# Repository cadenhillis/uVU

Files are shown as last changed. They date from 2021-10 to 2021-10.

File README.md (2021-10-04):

# uVU
A tiny analog VU meter

Uses the LM3915 to do a fun little VU display on an LED bargraph.

The pcb is a little hard to assemble, but bending the bargraph's pins out before soldering everything helps.

I didn't get great results with the two tuning pots -- they seemed to almost fight eachother.
Maybe adding some smoothing to make the sound wave more DC-like or only having 1 pot in the future will help things.

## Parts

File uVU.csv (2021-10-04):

Source: | E:\Projects\8. Micro VU Meter and BMS\uVU\uVU.sch
Date: | 6/15/2021 8:17:00 PM
Tool: | Eeschema (5.1.9)-1
Generator: | C:\Program Files\KiCad\bin\scripting\plugins/bom_csv_grouped_by_value.py
Component Count: | 19
Individual Components:
Item | Qty | Reference(s) | Value | LibPart | Footprint | Datasheet
 |  | C1 | 10uF | Device:CP1 | Capacitor_SMD:CP_Elec_4x3 | 865090140001
 |  | C2 | 10uF | Device:CP1 | Capacitor_SMD:CP_Elec_4x3 | 865090140001
 |  | C3 | 10uF | Device:CP1 | Capacitor_SMD:CP_Elec_4x3 | 865090140001
 |  | C4 | 47nF | Device:C | Capacitor_SMD:C_0603_1608Metric | ~
 |  | C5 | 10uF | Device:CP1 | Capacitor_SMD:CP_Elec_4x3 | 865090140001
 |  | C6 | 0.1uF | Device:C | Capacitor_SMD:C_0603_1608Metric | ~
 |  | D1 | DC10 | My_Library:DC10 | My_Library:DIP-16_W10.16mm
 |  | H1 | M2.2 | Mechanical:MountingHole | MountingHole:MountingHole_2.2mm_M2 | ~
 |  | H2 | M2.5 | Mechanical:MountingHole | MountingHole:MountingHole_2.2mm_M2 | ~
 |  | J1 | SSW-102-01-T-S | Connector_Generic:Conn_01x02 | Connector_PinHeader_2.54mm:PinHeader_1x02_P2.54mm_Vertical | ~
 |  | MK1 | CMA-6542PF | Device:Microphone | My_Library:CMA-6542PF | ~
 |  | R1 | 2.2k | Device:R_US | Resistor_SMD:R_0603_1608Metric | ~
 |  | R2 | 10R | Device:R_US | Resistor_SMD:R_0603_1608Metric | Resistor_SMD:R_0603_1608Metric
 |  | R3 | 10k | Device:R_US | Resistor_SMD:R_0603_1608Metric
 |  | R4 | 1k | Device:R_US | Resistor_SMD:R_0603_1608Metric | Resistor_SMD:R_0603_1608Metric
 |  | RV1 | 10k | Device:R_POT_US | Potentiometer_SMD:Potentiometer_Bourns_TC33X_Vertical | TC33X-1-103E
 |  | RV2 | 10k | Device:R_POT_US | Potentiometer_SMD:Potentiometer_Bourns_TC33X_Vertical | TC33X-1-103E
 |  | U1 | LM386MMX-1/NOPB | Amplifier_Audio:LM386 | Package_SO:TSSOP-8_4.4x3mm_P0.65mm | http://www.ti.com/lit/ds/symlink/lm386.pdf
 |  | U2 | LM3915 | My_Library:LM3915 | Package_DIP:DIP-18_W7.62mm
Collated Components:
Item | Qty | Reference(s) | Value | LibPart | Footprint | Datasheet
1 | 4 | C1, C2, C3, C5 | 10uF | Device:CP1 | Capacitor_SMD:CP_Elec_4x3 | 865090140001
2 | 1 | C4 | 47nF | Device:C | Capacitor_SMD:C_0603_1608Metric | ~
3 | 1 | C6 | 0.1uF | Device:C | Capacitor_SMD:C_0603_1608Metric | ~
4 | 1 | D1 | DC10 | My_Library:DC10 | My_Library:DIP-16_W10.16mm
5 | 1 | H1 | M2.2 | Mechanical:MountingHole | MountingHole:MountingHole_2.2mm_M2 | ~
6 | 1 | H2 | M2.5 | Mechanical:MountingHole | MountingHole:MountingHole_2.2mm_M2 | ~
7 | 1 | J1 | SSW-102-01-T-S | Connector_Generic:Conn_01x02 | Connector_PinHeader_2.54mm:PinHeader_1x02_P2.54mm_Vertical | ~
8 | 1 | MK1 | CMA-6542PF | Device:Microphone | My_Library:CMA-6542PF | ~
9 | 1 | R1 | 2.2k | Device:R_US | Resistor_SMD:R_0603_1608Metric | ~
10 | 1 | R2 | 10R | Device:R_US | Resistor_SMD:R_0603_1608Metric | Resistor_SMD:R_0603_1608Metric
11 | 1 | R3 | 10k | Device:R_US | Resistor_SMD:R_0603_1608Metric
12 | 1 | R4 | 1k | Device:R_US | Resistor_SMD:R_0603_1608Metric | Resistor_SMD:R_0603_1608Metric
13 | 2 | RV1, RV2 | 10k | Device:R_POT_US | Potentiometer_SMD:Potentiometer_Bourns_TC33X_Vertical | TC33X-1-103E
14 | 1 | U1 | LM386MMX-1/NOPB | Amplifier_Audio:LM386 | Package_SO:TSSOP-8_4.4x3mm_P0.65mm | http://www.ti.com/lit/ds/symlink/lm386.pdf
15 | 1 | U2 | LM3915 | My_Library:LM3915 | Package_DIP:DIP-18_W7.62mm

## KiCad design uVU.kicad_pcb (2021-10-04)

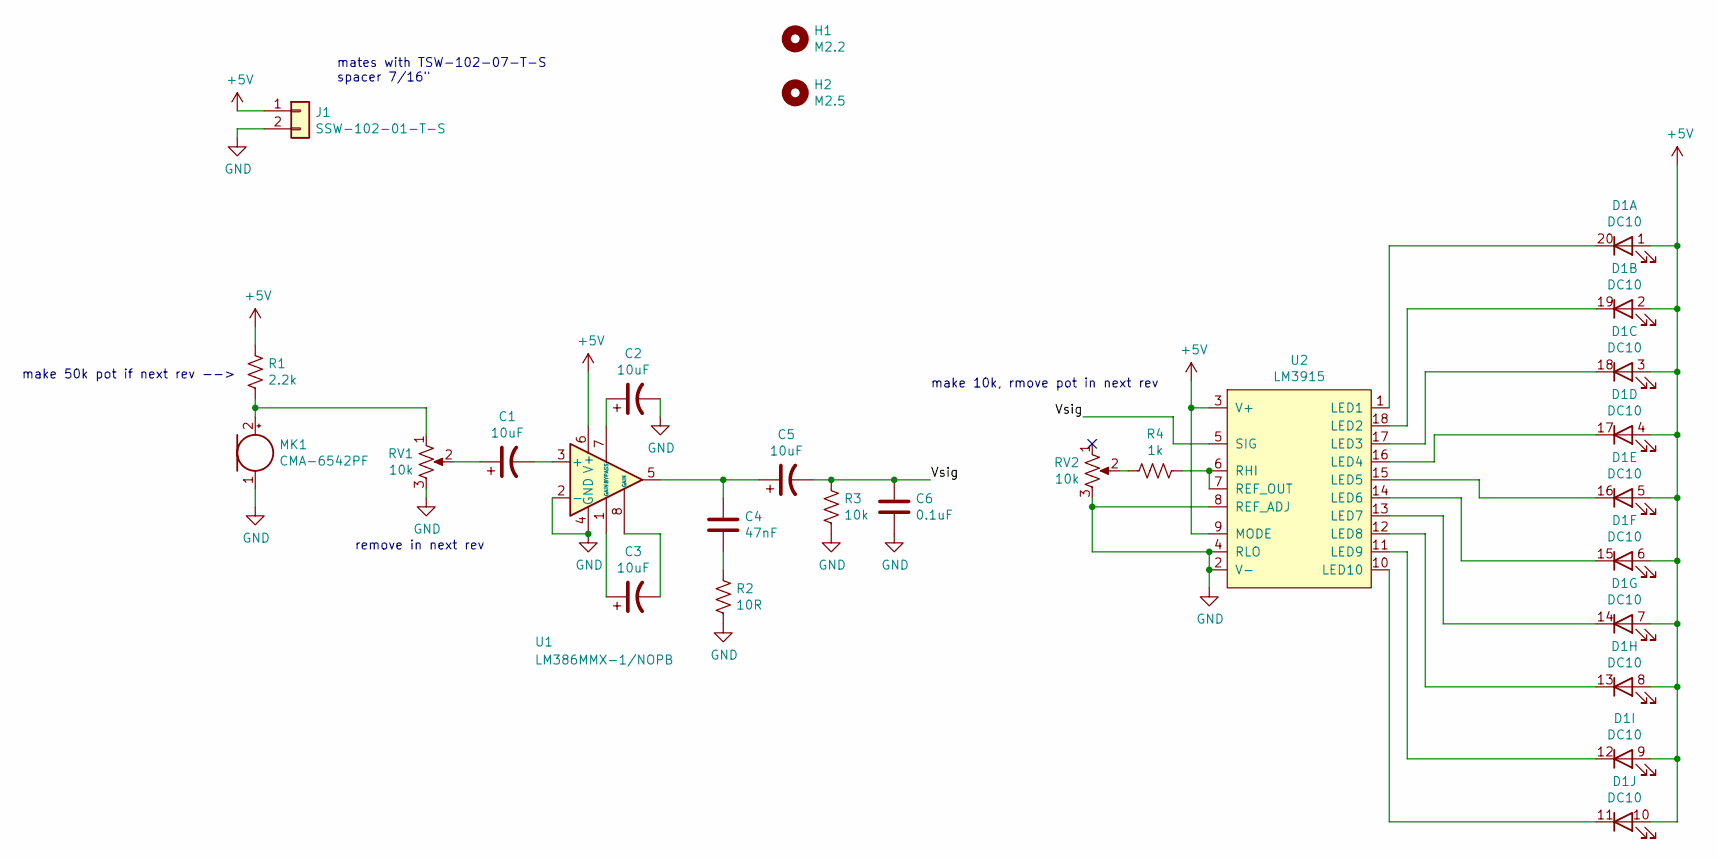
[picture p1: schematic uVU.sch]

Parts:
C1, C2, C3, C5: 10uF; CP_Elec_4x3
C4: 47nF; C_0603_1608Metric
C6: 0.1uF; C_0603_1608Metric
D1: DC10; DIP-16_W10.16mm
H1: M2.2; MountingHole_2.2mm_M2
H2: M2.5; MountingHole_2.2mm_M2
J1: SSW-102-01-T-S; PinHeader_1x02_P2.54mm_Vertical
MK1: CMA-6542PF
R1: 2.2k; R_0603_1608Metric
R2: 10R; R_0603_1608Metric
R3: 10k; R_0603_1608Metric
R4: 1k; R_0603_1608Metric
RV1, RV2: 10k; Potentiometer_Bourns_TC33X_Vertical
U1: LM386MMX-1/NOPB; TSSOP-8_4.4x3mm_P0.65mm
U2: LM3915; DIP-18_W7.62mm

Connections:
+5V: D1.1, D1.2, D1.3, D1.4, D1.5, D1.6, D1.7, D1.8, D1.9, D1.10, J1.1, R1.1, U1.6 (V+), U2.3 (V+), U2.9 (MODE)
/Vsig: C5.2, C6.1, R3.1, U2.5 (SIG)
GND: C2.2, C6.2, J1.2, MK1.1 (-), R2.2, R3.2, RV1.3, RV2.3, U1.2 (-), U1.4 (GND), U2.2 (V-), U2.4 (RLO), U2.8 (REF_ADJ); also elsewhere on the board
unnamed: C1.1, RV1.2
unnamed: C1.2, U1.3 (+)
unnamed: C2.1, U1.7 (BYPASS)
unnamed: C3.1, U1.1 (GAIN)
unnamed: C3.2, U1.8 (GAIN)
unnamed: C4.1, C5.1, U1.5
unnamed: C4.2, R2.1
unnamed: D1.11, U2.10 (LED10)
unnamed: D1.12, U2.11 (LED9)
unnamed: D1.13, U2.12 (LED8)
unnamed: D1.14, U2.13 (LED7)
unnamed: D1.15, U2.14 (LED6)
unnamed: D1.16, U2.15 (LED5)
unnamed: D1.17, U2.16 (LED4)
unnamed: D1.18, U2.17 (LED3)
unnamed: D1.19, U2.18 (LED2)
unnamed: D1.20, U2.1 (LED1)
unnamed 20: MK1.2 (+), R1.2, RV1.1; also elsewhere on the board
unnamed: R4.1, U2.6 (RHI), U2.7 (REF_OUT)
unnamed: R4.2, RV2.2

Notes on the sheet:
mates with TSW-102-07-T-S spacer 7/16"
make 50k pot if next rev -->
remove in next rev
make 10k, rmove pot in next rev

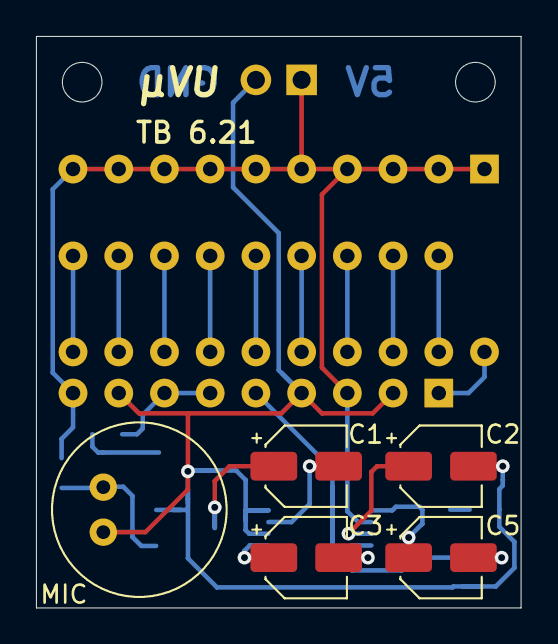
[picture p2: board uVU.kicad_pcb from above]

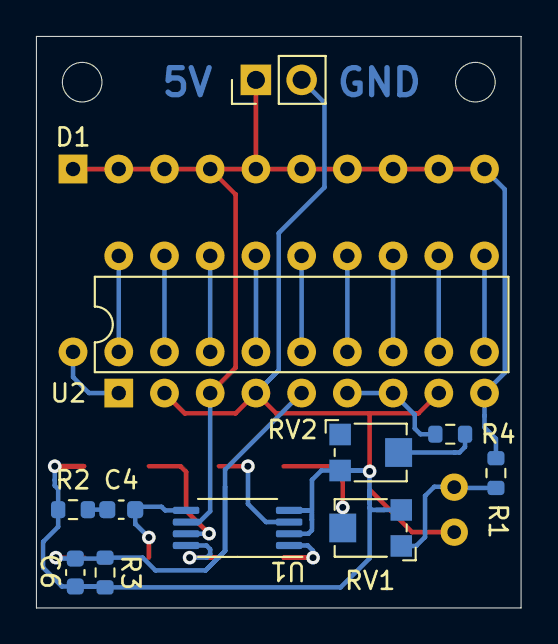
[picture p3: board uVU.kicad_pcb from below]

Board: 2 copper layers, 26.9 x 31.8 mm, 19 parts (11 on the bottom side), 23 nets.

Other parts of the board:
MIC: CMA-6542PF

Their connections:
GND: MIC.1; also elsewhere on the board
unnamed 20: MIC.2; also elsewhere on the board
